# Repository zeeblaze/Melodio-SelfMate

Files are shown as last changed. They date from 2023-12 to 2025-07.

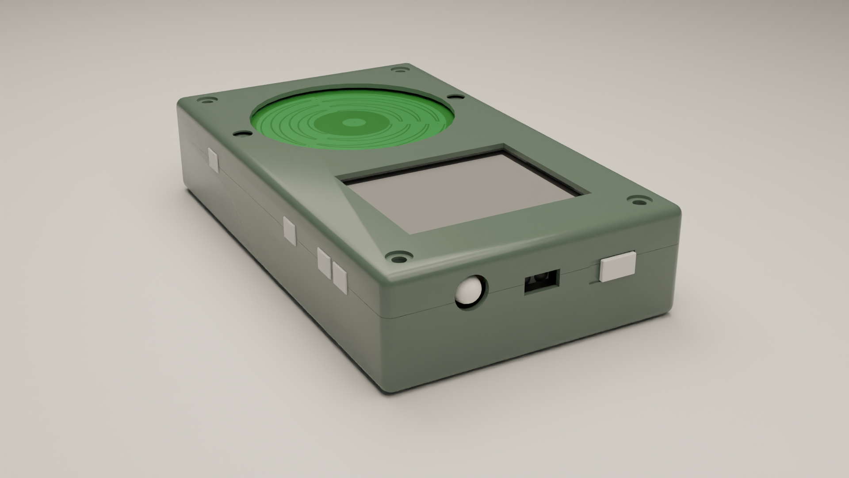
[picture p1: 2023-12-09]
Melodio_renders/R1.png

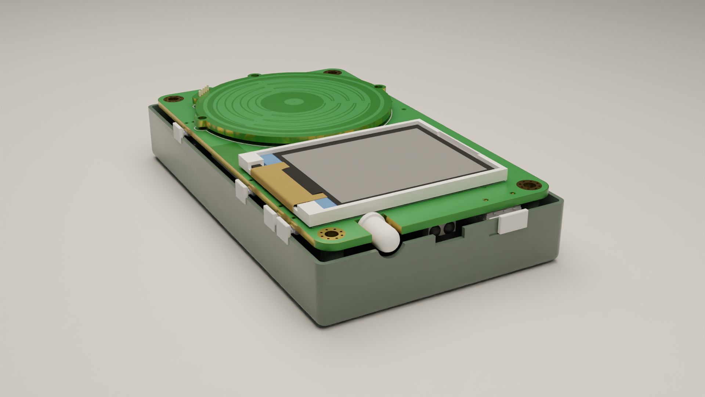
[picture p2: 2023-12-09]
Melodio_renders/R2.png

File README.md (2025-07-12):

Melodio Self-Mate is a cutting-edge portable electronic device designed to revolutionize your music experience. At its core lies the powerful ESP32-S3, providing unparalleled performance and versatility. This innovative gadget seamlessly combines music playback, Spotify streaming, and programmability, making it the go-to choice for music enthusiasts and programmers that wants to look into how smart devices work.

This portable programmable device packs a lot into its little brain, including and not Limited to, IR(receiver and transmitter), High speed mass storage, SD card, touch wheel technology, USB switch, which gives it a endless possibility of what is achievable with it. 

# KEY FEATURES:

ESP32-S3: Melodio makes use of ESP32-S3 as its heart which ensures high-performance and efficiency, enabling a seamless user experience.

DAC: Melodio uses the high quality TI PCM5102A 32bit, 348kHz, 112dB audio stereo DAC to output digital audio signal coming from the ESP32-S3 as analog signal for the headphone amplifier.

HEADPHONE AMP: High quality analog audio signal coming from the PCM5102A is received by yet another high quality headphone amplifier from Texas Instrument, TI TPA6130A2 138-mW stereo analog input headphone amplifier with I2C control interface, which then output its amplified audio signal to a headphone jack. The I2c control interface of this amplifier allows the volume of the amplifier output audio to be controlled from the software.

DISPLAY: Melodio implements a 1.8 inch 128x160 ST7735 TFT display as a visual interface.

MASS STORAGE

USB SWITCH

BUTTONS: There are four buttons on the side of Melodio:

Volume Up
Volume Down
Boot_0(for entering programming mode)
Reset
Volume Up and Volume Down buttons control the  headphone amp directly from software, so their functionalities can be altered and hardcode the amplifier volume directly from software. 

SLIDER SWITCHES

SPOTIFY CONNECT

MUSIC PLAYER

STEMMA QT CONNECTOR

IR (Transmitter and Receiver)

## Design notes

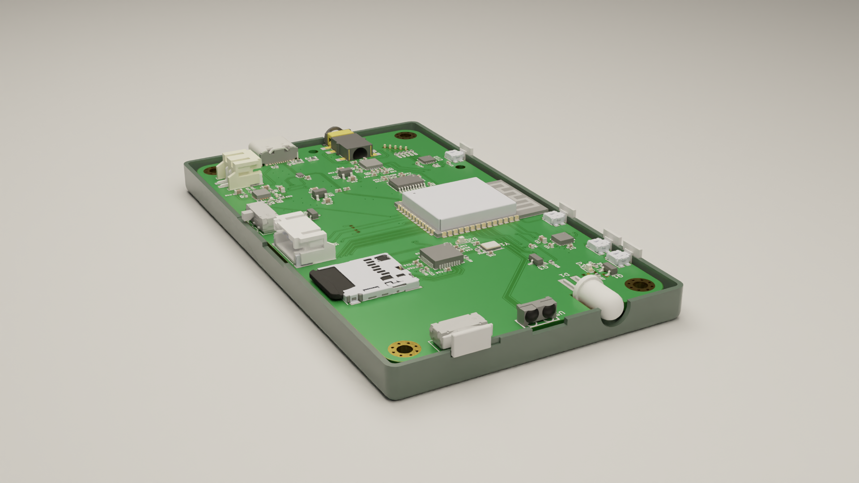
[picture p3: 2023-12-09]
Melodio_renders/R4.png

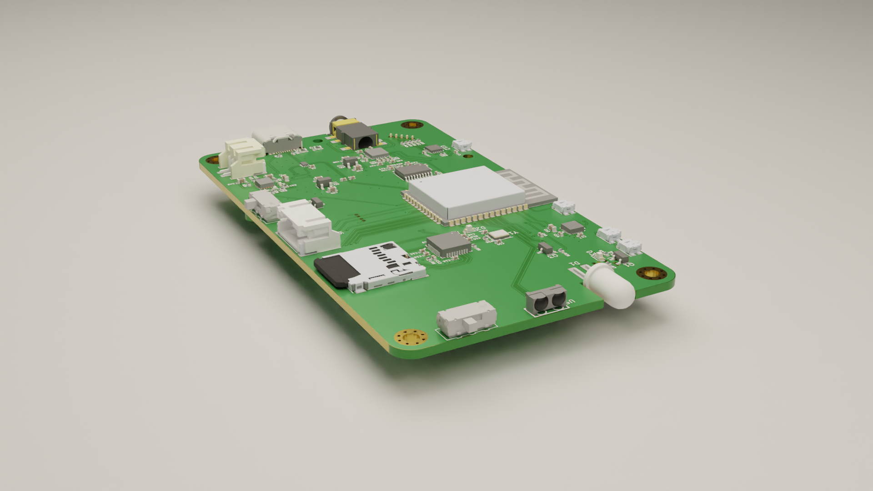
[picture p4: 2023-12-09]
Melodio_renders/R3.png

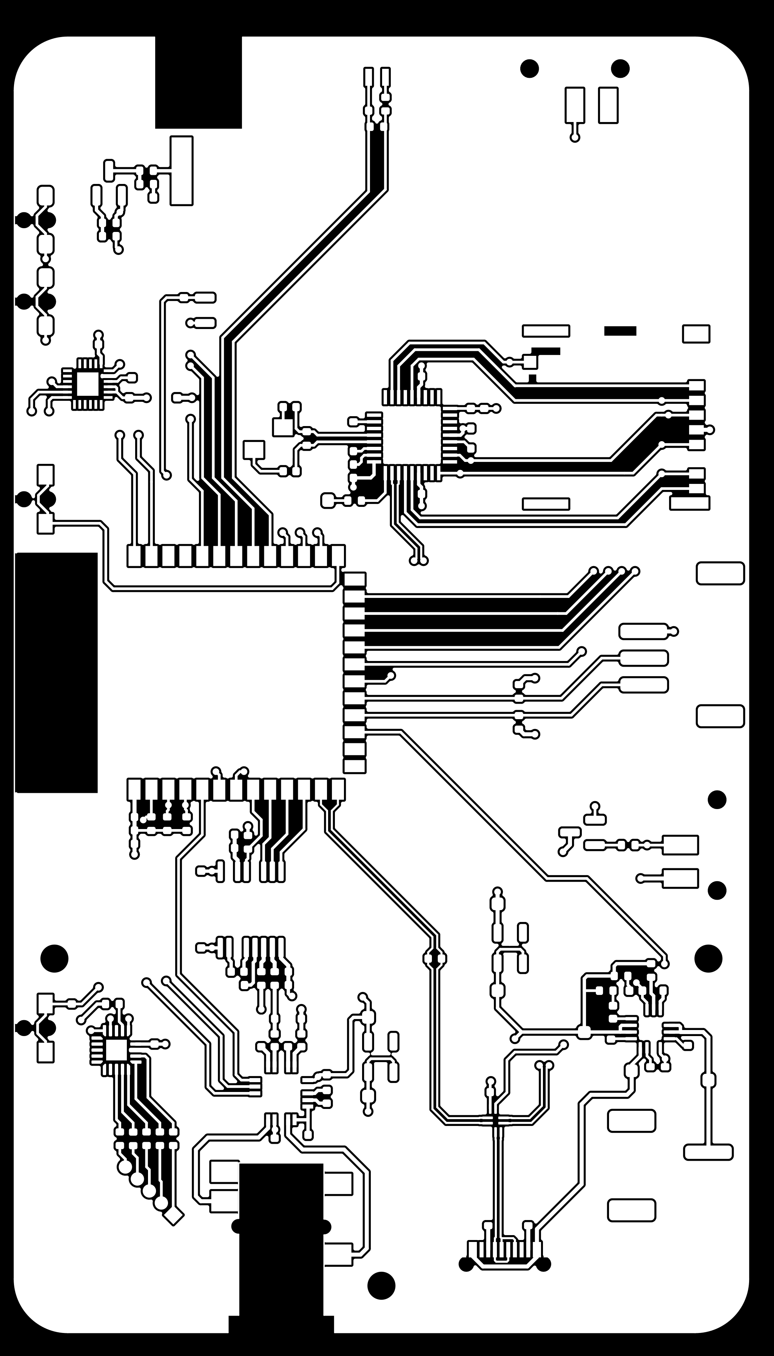
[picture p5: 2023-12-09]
Output_PNGs/pcb_F_CU.png

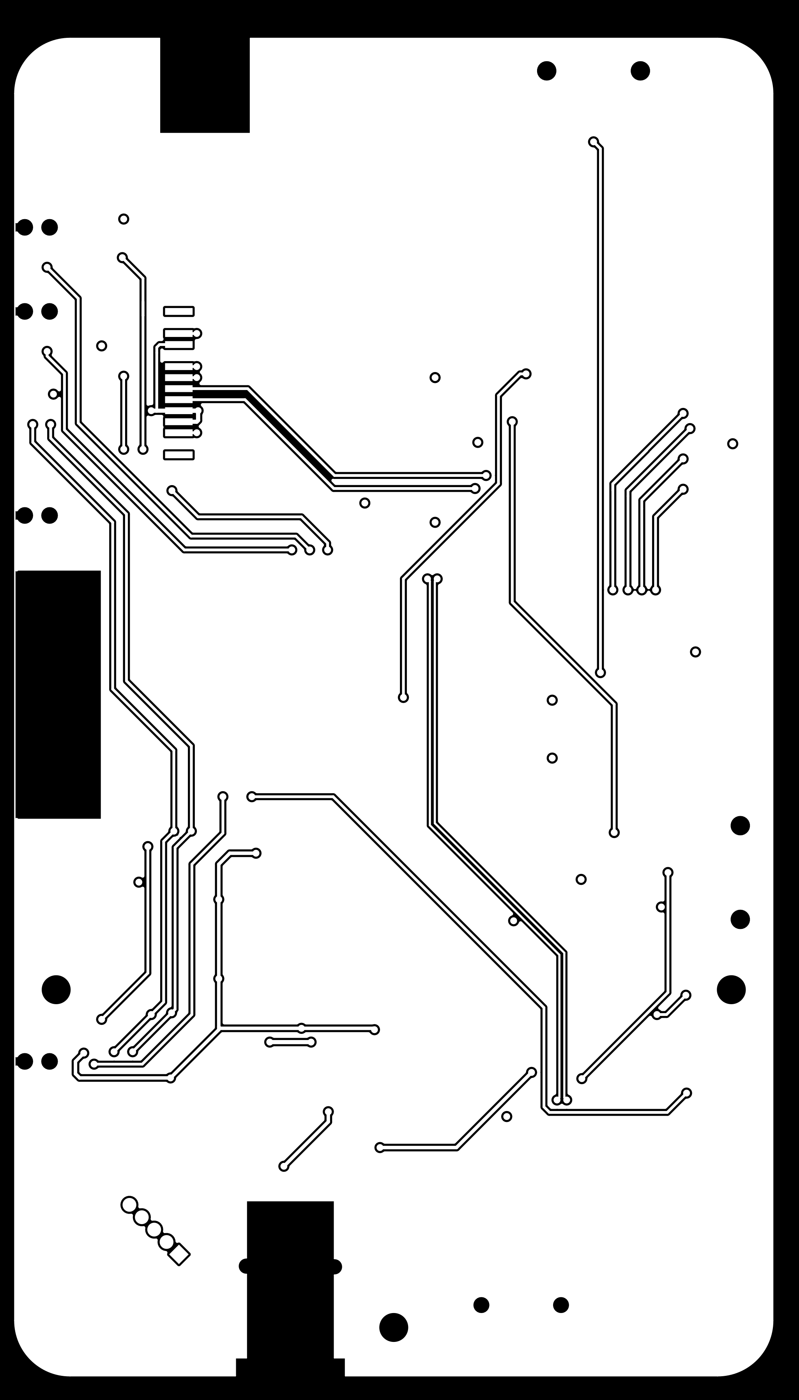
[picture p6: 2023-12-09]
Output_PNGs/pcb_B_Cu.png

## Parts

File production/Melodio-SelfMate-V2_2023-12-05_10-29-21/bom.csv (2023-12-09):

Designator | Footprint | Quantity | Value | LCSC Part #
C1, C11, C13 | 0402 | 3 | 10u
C10, C2, C20, C22, C35, C4, C5, C8, C9 | 0402 | 9 | 100n
C12, C17, C19, C21, C23, C24, C25, C26, C27, C28, C29, C3, C30, C31, C32, C33, C34, C36, C37, C38, C39, C44 | 0402 | 22 | 1u
C14, C16 | 0402 | 2 | 2n2
C15, C18 | 0402 | 2 | DNP
C40, C41, C42, C43, C45, C46, C47 | 0603 | 7 | 10u
C6, C7 | 0402 | 2 | 2u2
D1 | 0603 | 1 | GREEN
D2 | LED_5mm_Side_Mount | 1 | SFH4346
D3, D4 | 0402 | 2 | RED
D5 | 0402 | 1 | GREEN
H1, H2, H3, H4 | MountingHole_2.7mm_M2.5_Pad_Via | 4 | MountingHole_Pad
J1 | JST_PH_S4B-PH-SM4-TB_1x04-1MP_P2.00mm_Horizontal | 1 | STEMMA_QT
J2 | SMD_PJ-399E-6A | 1 | ~
J3 | USB_C_Receptacle_GCT_USB4105-xx-A_16P_TopMnt_Horizontal | 1 | USB_C_Receptacle_USB2.0
J4 | JST_PH_S2B-PH-SM4-TB_1x02-1MP_P2.00mm_Horizontal | 1 | BATTERY_CONN
J5 | PinHeader_1x05_P1.27mm_Vertical | 1 | Qtouch
J6 | MOLEX_503398-1892 | 1 | Micro_SD_Card_Det2
Q1, Q2, Q3 | SOT-23 | 3 | DMG2301L
R1, R11, R14, R17, R18, R2, R21, R22, R23, R25, R26, R27, R28, R29, R33, R34, R37, R8 | 0402 | 18 | 10k
R10 | 0402 | 1 | 330R
R12, R15, R31, R32, R9 | 0402 | 5 | 1k
R13 | 0402 | 1 | 200R
R16, R7 | 0402 | 2 | 1mR
R19, R20 | 0402 | 2 | 5k1
R24, R30 | 0402 | 2 | 1k1
R3, R4 | 0402 | 2 | 470R
R35, R36, R5, R6 | 0402 | 4 | 4k7
SW1 | SW_SPST_EVQP7C | 1 | BOOT
SW2 | SW_SPST_EVQP7C | 1 | RST
SW3, SW6 | SW_SPDT_CK-JS102011SAQN | 2 | SW_USB
SW4 | SW_SPST_EVQP7C | 1 | VOL_UP
SW5 | SW_SPST_EVQP7C | 1 | VOL_DOWN
U1 | TSSOP-20_4.4x6.5mm_P0.65mm | 1 | PCM5102
U10 | VQFN-16-1EP_3x3mm_P0.5mm_EP1.6x1.6mm | 1 | BQ24075RGT
U11 | VQFN-20-1EP_3x3mm_P0.45mm_EP1.55x1.55mm | 1 | ~
U12, U9 | SOT-23-5 | 2 | AP2112K-3.3
U2 | ESP32-S3-WROOM-1-N8R8 | 1 | ESP32-S3-WROOM-1-N4R4
U3 | UQFN-10_1.3x1.8mm_P0.4mm | 1 | USB3740B-AI2
U4 | MPU-6500 | 1 | MPU-6500
U5 | TPA6130A2RTJR | 1 | TPA6130A2RTJR | TPA6130A2RTJR
U6 | USB2244-AEZG-06 | 1 | USB2244-AEZG-06
U7 | IRM-V838M3-C-TR1 | 1 | ~
U8 | 1.8inch_TFT_128x160 | 1 | ~
Y1 | Crystal_SMD_3225-4Pin_3.2x2.5mm | 1 | 24MHz

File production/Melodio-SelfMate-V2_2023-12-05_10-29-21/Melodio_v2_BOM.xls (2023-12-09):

Manufacturer Part Number* | Qty* | Designator* | Customer Supply | Customer Remark
C0402X5R106M100NTBF | 3 | C1, C11, C13 | 10u | 402
0402B104J100NT | 9 | C10, C2, C20, C22, C35, C4, C5, C8, C9 | 100n | 402
0402X105K160NT | 22 | C12, C17, C19, C21, C23, C24, C25, C26, C27, C28, C29, C3, C30, C31, C32, C33, C34, C36, C37, C38, C39, C44 | 1u | 402
CC0402KRX7R6BB222 | 2 | C14, C16 | 2n2 | 402
DNP | 2 | C15, C18 | DNP | 402
TCC0603X5R106K250CT | 7 | C40, C41, C42, C43, C45, C46, C47 | 10u | 603
0402X225M6R3NT | 2 | C6, C7 | 2u2 | 402
LTST-C191TGKT | 1 | D1 | GREEN | 603
IR383-A | 1 | D2 | SFH4346 | LED_5mm_Side_Mount
XL-1005SURC | 2 | D3, D4 | RED | 402
LTST-C281KGKT | 1 | D5 | GREEN | 402
DNP | 4 | H1, H2, H3, H4 | MountingHole_Pad | MountingHole_2.7mm_M2.5_Pad_Via
S4B-PH-SM4-TB(LF)(SN) | 1 | J1 | STEMMA_QT | JST_PH_S4B-PH-SM4-TB_1x04-1MP_P2.00mm_Horizontal
PJ-399E-6A | 1 | J2 | ~ | SMD_PJ-399E-6A
USB4105-GF-A | 1 | J3 | USB_C_Receptacle_USB2.0 | USB_C_Receptacle_GCT_USB4105-xx-A_16P_TopMnt_Horizontal
S2B-PH-SM4-TB(LF)(SN) | 1 | J4 | BATTERY_CONN | JST_PH_S2B-PH-SM4-TB_1x02-1MP_P2.00mm_Horizontal
Pin headers XPB-210-1S-1*12P | 1 | J5 | Qtouch | PinHeader_1x05_P1.27mm_Vertical
MOLEX-5033981892 | 1 | J6 | Micro_SD_Card_Det2 | MOLEX_503398-1892
DMG2301L-7 | 3 | Q1, Q2, Q3 | DMG2301L | SOT-23
RC0402FR-0710KP | 18 | R1, R11, R14, R17, R18, R2, R21, R22, R23, R25, R26, R27, R28, R29, R33, R34, R37, R8 | 10k | 402
ARG02DTC3300 | 1 | R10 | 330R | 402
RC0402DR-071KL | 5 | R12, R15, R31, R32, R9 | 1k | 402
AC0402JR-07200RL | 1 | R13 | 200R | 402
AC0402JR-071ML | 2 | R16, R7 | 1mR | 402
RC0402JR-075K1L | 2 | R19, R20 | 5k1 | 402
RC0402FR-071K1L | 2 | R24, R30 | 1k1 | 402
AC0402JR-07470RL | 2 | R3, R4 | 470R | 402
RC0402DR-074K7L | 4 | R35, R36, R5, R6 | 4k7 | 402
EVQP7C01P | 1 | SW1 | BOOT | SW_SPST_EVQP7C
EVQP7C01P | 1 | SW2 | RST | SW_SPST_EVQP7C
C&K JS102011SAQN | 2 | SW3, SW6 | SW_USB | SW_SPDT_CK-JS102011SAQN
EVQP7C01P | 1 | SW4 | VOL_UP | SW_SPST_EVQP7C
EVQP7C01P | 1 | SW5 | VOL_DOWN | SW_SPST_EVQP7C
PCM5102APWR | 1 | U1 | PCM5102 | TSSOP-20_4.4x6.5mm_P0.65mm
DNP | 1 | U10 | BQ24075RGT | VQFN-16-1EP_3x3mm_P0.5mm_EP1.6x1.6mm
AT42QT2120-MMH | 1 | U11 | ~ | VQFN-20-1EP_3x3mm_P0.45mm_EP1.55x1.55mm
AP2112K-3.3TRG1 | 2 | U12, U9 | AP2112K-3.3 | SOT-23-5
ESP32-S3-WROOM-1-N4R4 | 1 | U2 | ESP32-S3-WROOM-1-N4R4 | ESP32-S3-WROOM-1-N4R4
USB3740B-AI2 | 1 | U3 | USB3740B-AI2 | UQFN-10_1.3x1.8mm_P0.4mm
DNP | 1 | U4 | MPU-6500 | MPU-6500
TPA6130A2RTJR | 1 | U5 | TPA6130A2RTJR | TPA6130A2RTJR
USB2244-AEZG-06 | 1 | U6 | USB2244-AEZG-06 | USB2244-AEZG-06
IRM-V838M3-C-TR1 | 1 | U7 | ~ | IRM-V838M3-C-TR1
DNP | 1 | U8 | ~ | 1.8inch_TFT_128x160
XXCBCLNAOF-24MHz | 1 | Y1 | 24MHz | Crystal_SMD_3225-4Pin_3.2x2.5mm

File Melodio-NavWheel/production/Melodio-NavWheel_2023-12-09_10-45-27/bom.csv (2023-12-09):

Designator | Footprint | Quantity | Value | LCSC Part #
J1 | qtouch-wheel | 1 | Wheel
J2 | qtouch-button | 1 | Sel
J3 | qtouch-guard | 1 | Guard
J4 | PinHeader_1x05_P1.27mm_Vertical | 1 | Interface

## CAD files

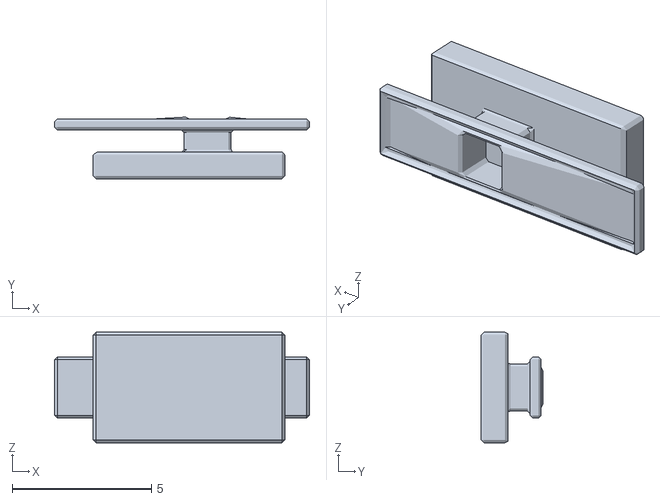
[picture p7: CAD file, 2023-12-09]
Melodio 3D print/Melodio_Case_Slider.stl
9.16 x 2.22 x 3.97

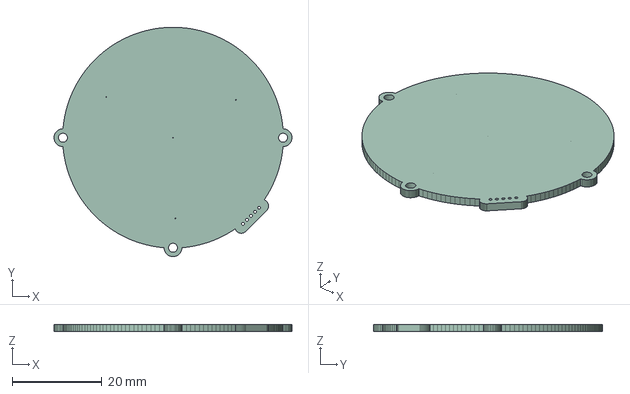
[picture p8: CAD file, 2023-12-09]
Melodio-NavWheel/Melodio-NavWheel.step
53.0 x 51.1 x 1.60 mm

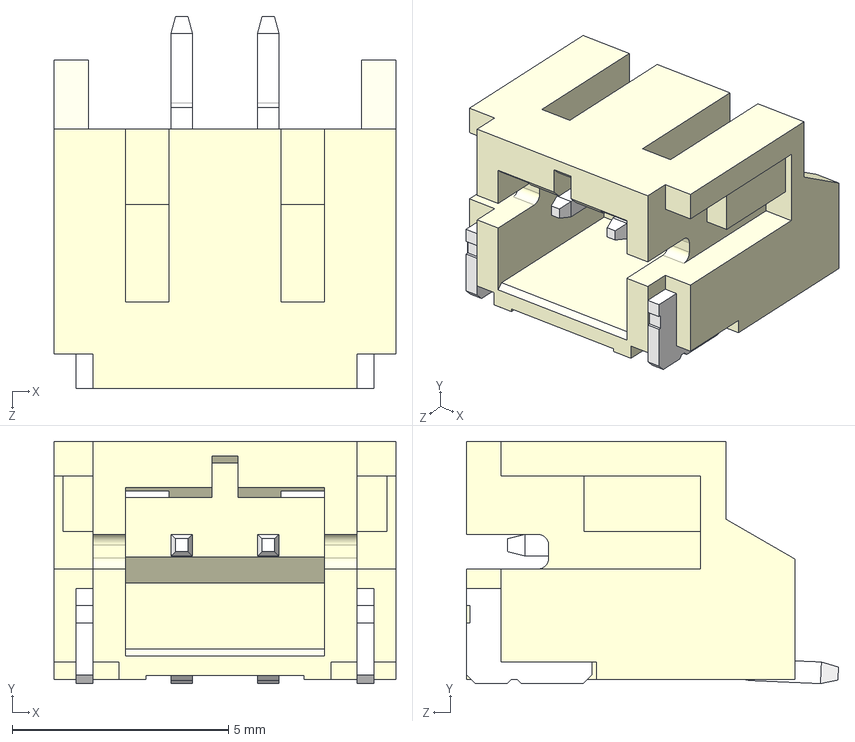
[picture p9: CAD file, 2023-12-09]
Melodio-SelfMate-V2-3Dmodels/S2B-PH-SM4-TB(LF)(SN)--3DModel-STEP-56544.STEP
7.90 x 5.60 x 8.60 mm

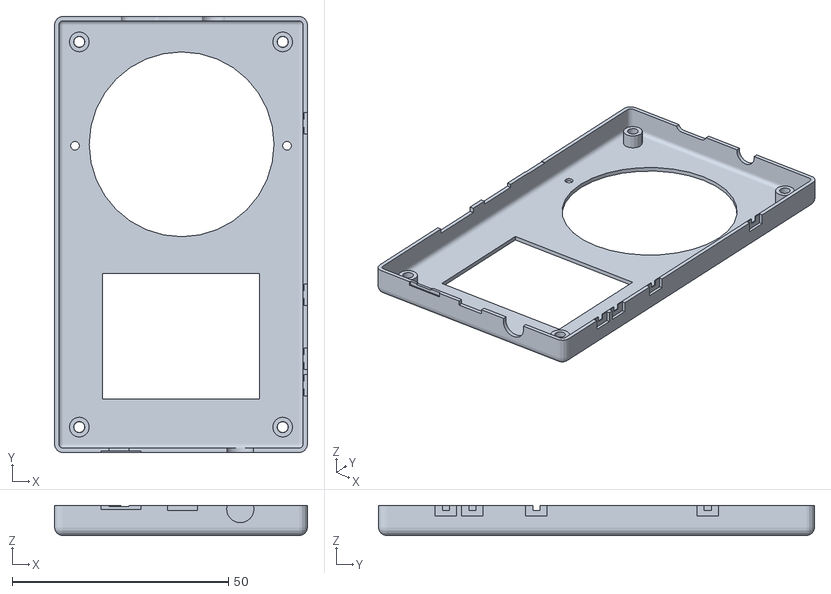
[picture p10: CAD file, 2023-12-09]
Melodio 3D print/Melodio_Case_Top.stl
58.5 x 100.8 x 6.98

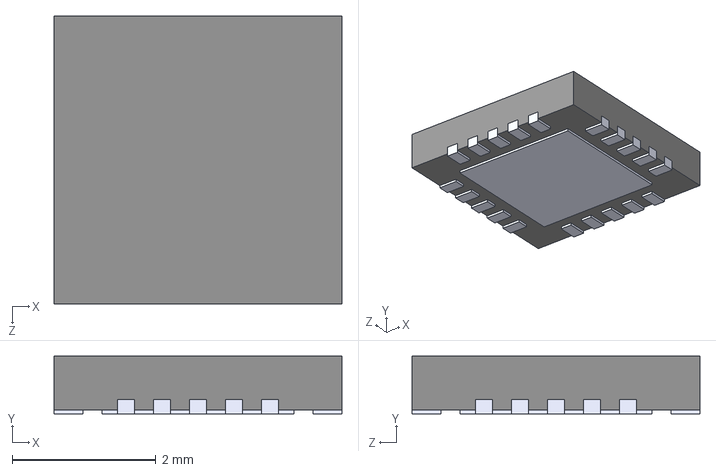
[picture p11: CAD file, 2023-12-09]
Melodio-SelfMate-V2-3Dmodels/TPA6130A2RTJR.step
4.00 x 0.8 x 4.00 mm

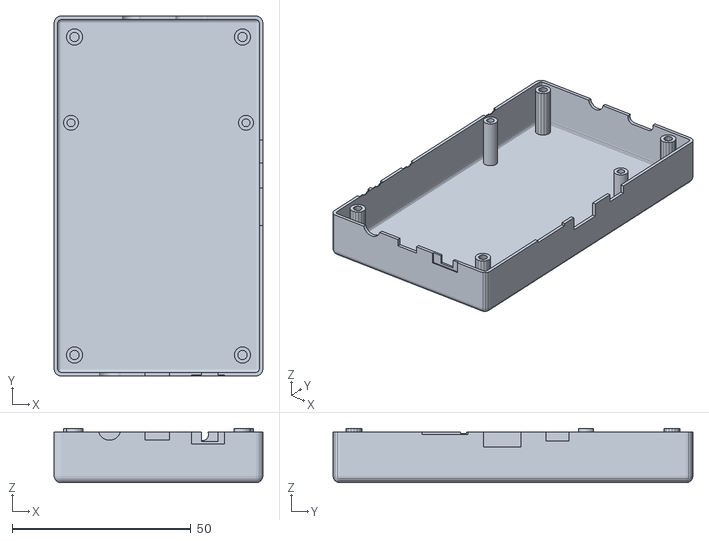
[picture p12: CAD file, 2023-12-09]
Melodio 3D print/Melodio_Case_Base.stl
58.5 x 100.8 x 15.3

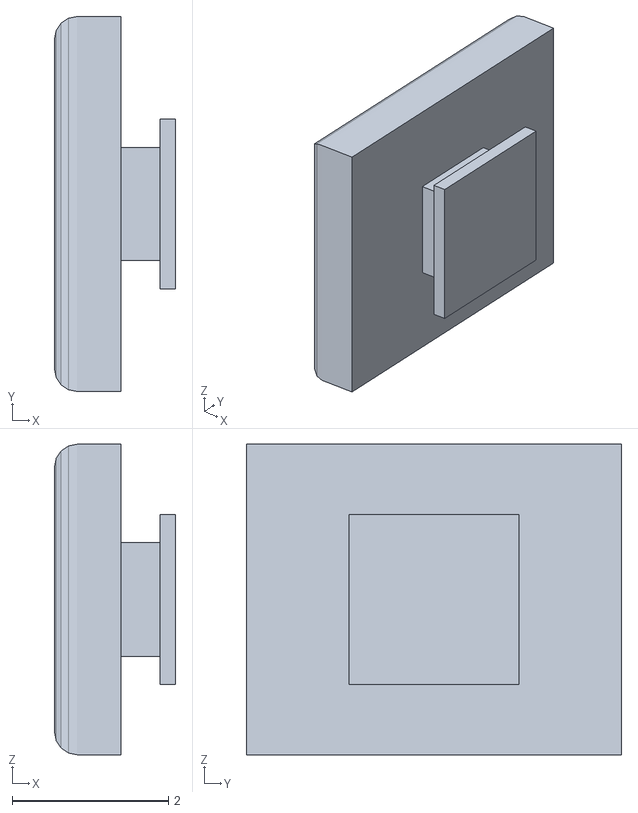
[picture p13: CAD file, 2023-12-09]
Melodio 3D print/Melodio_Case_Button.stl
1.55 x 4.80 x 3.98

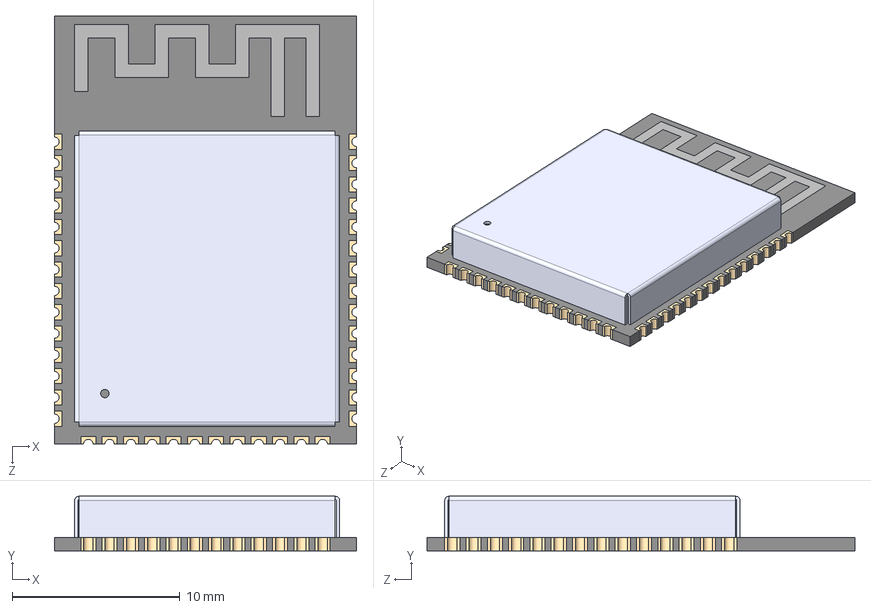
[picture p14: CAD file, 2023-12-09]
Melodio-SelfMate-V2-3Dmodels/ESP32-S3-WROOM-1-N8R8.step
18.0 x 3.25 x 25.5 mm

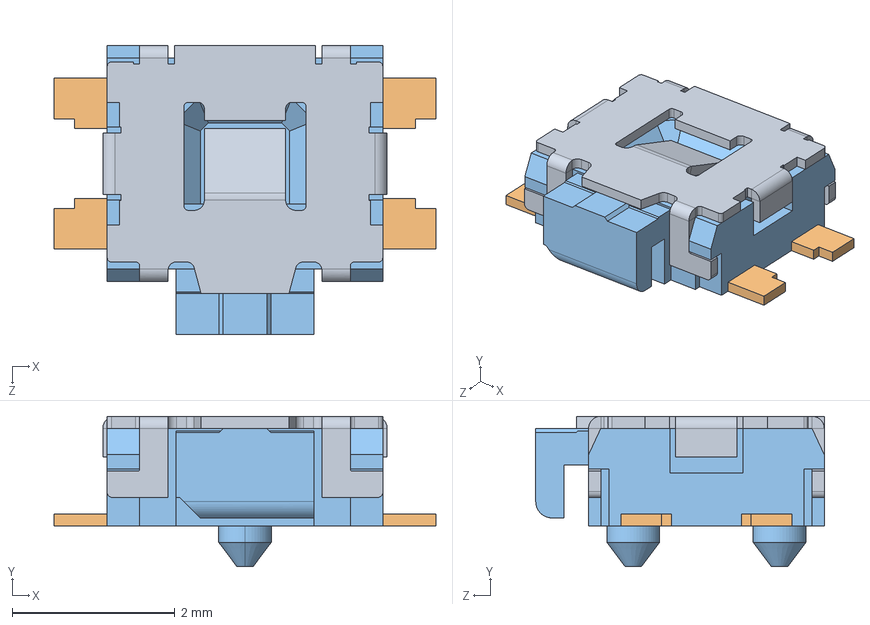
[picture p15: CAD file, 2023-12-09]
Melodio-SelfMate-V2-3Dmodels/EVQP7C01P--3DModel-STEP-269445.STEP
4.70 x 1.85 x 3.55 mm

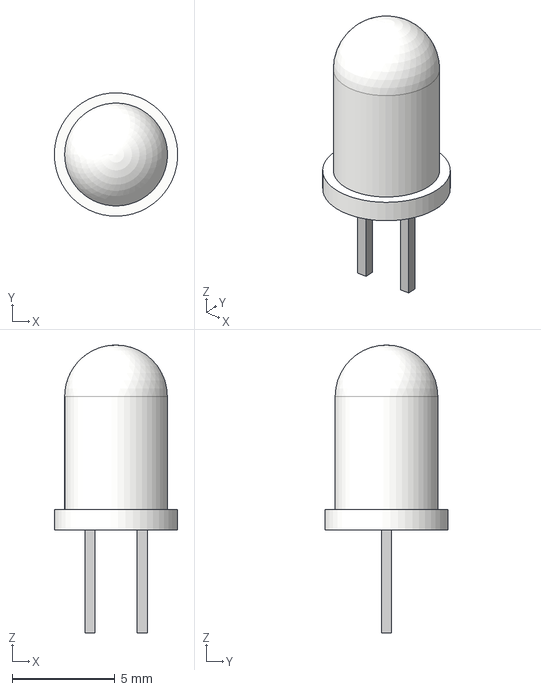
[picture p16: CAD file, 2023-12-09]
Melodio-SelfMate-V2-3Dmodels/Side Mount LED v1.step
5.99 x 6.00 x 14.0 mm

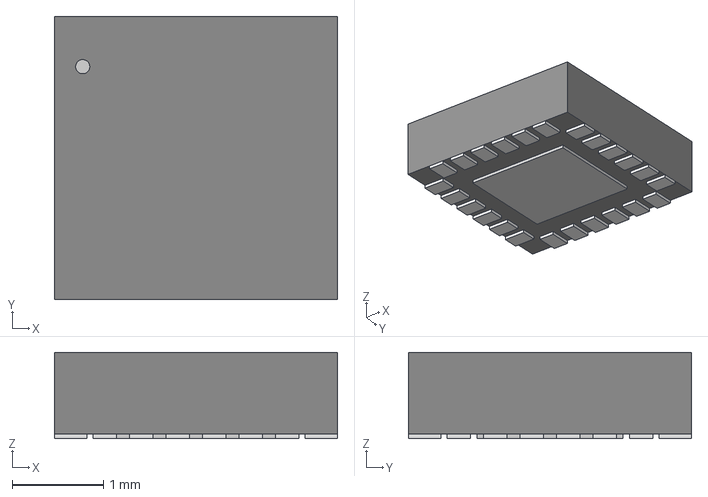
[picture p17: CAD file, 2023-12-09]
Melodio-SelfMate-V2-3Dmodels/MPU6500.step
3.10 x 3.10 x 0.942 mm

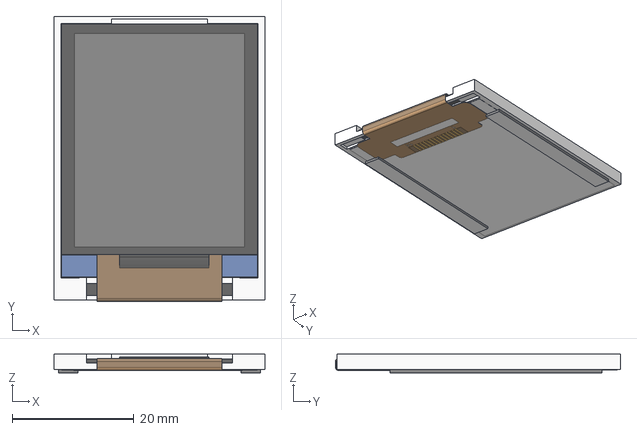
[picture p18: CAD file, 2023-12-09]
Melodio-SelfMate-V2-3Dmodels/LCD_TFT_1.8_SPI_ST7735.stp
34.7 x 46.9 x 3.07 mm

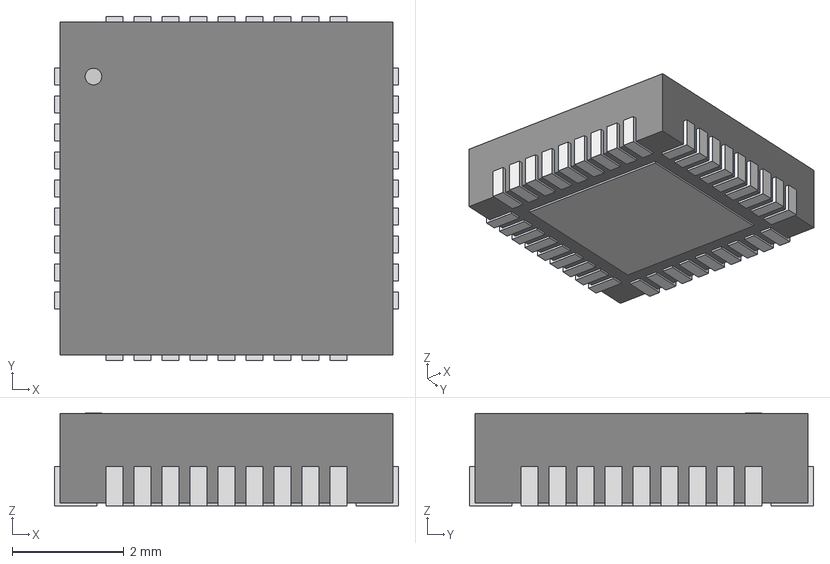
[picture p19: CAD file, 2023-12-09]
Melodio-SelfMate-V2-3Dmodels/USB2244-AEZG-06.step
6.15 x 6.15 x 1.65 mm

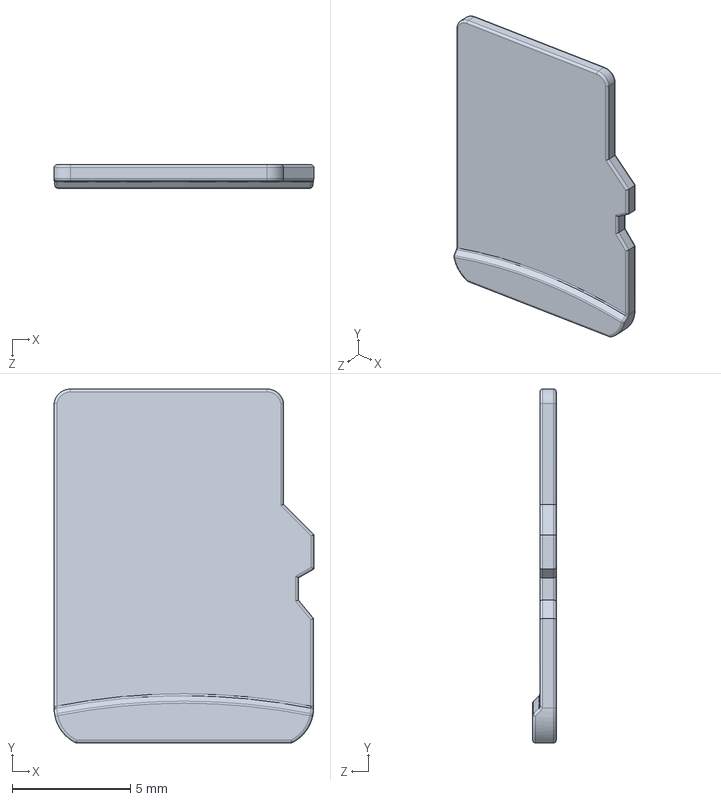
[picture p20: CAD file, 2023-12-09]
Melodio-SelfMate-V2-3Dmodels/Micro SD Card.STEP
11.0 x 15.0 x 1.00 mm

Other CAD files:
Melodio-SelfMate-V2-3Dmodels/S4B-PH-SM4-TB--3DModel-STEP-56544.STEP
Melodio-SelfMate-V2-3Dmodels/BQ24075RGTRG4.stp
Melodio-SelfMate-V2-3Dmodels/503398-1892.step
Melodio-SelfMate-V2-3Dmodels/JS102011SAQN--3DModel-Eagle-1.STEP

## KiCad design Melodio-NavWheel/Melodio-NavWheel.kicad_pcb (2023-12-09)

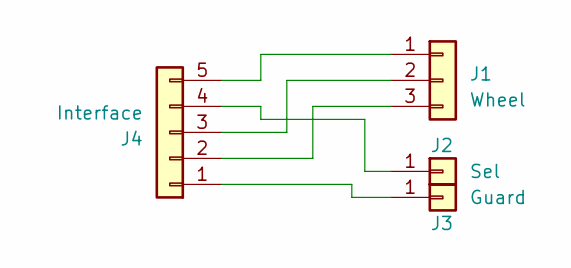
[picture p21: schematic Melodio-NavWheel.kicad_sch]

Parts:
J1: Wheel; qtouch-wheel
J2: Sel; qtouch-button
J3: Guard; qtouch-guard
J4: Interface; PinHeader_1x05_P1.27mm_Vertical

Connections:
unnamed: J1.1, J4.5
unnamed: J1.2, J4.3
unnamed: J1.3, J4.2
unnamed: J2.1, J4.4
unnamed: J3.1, J4.1

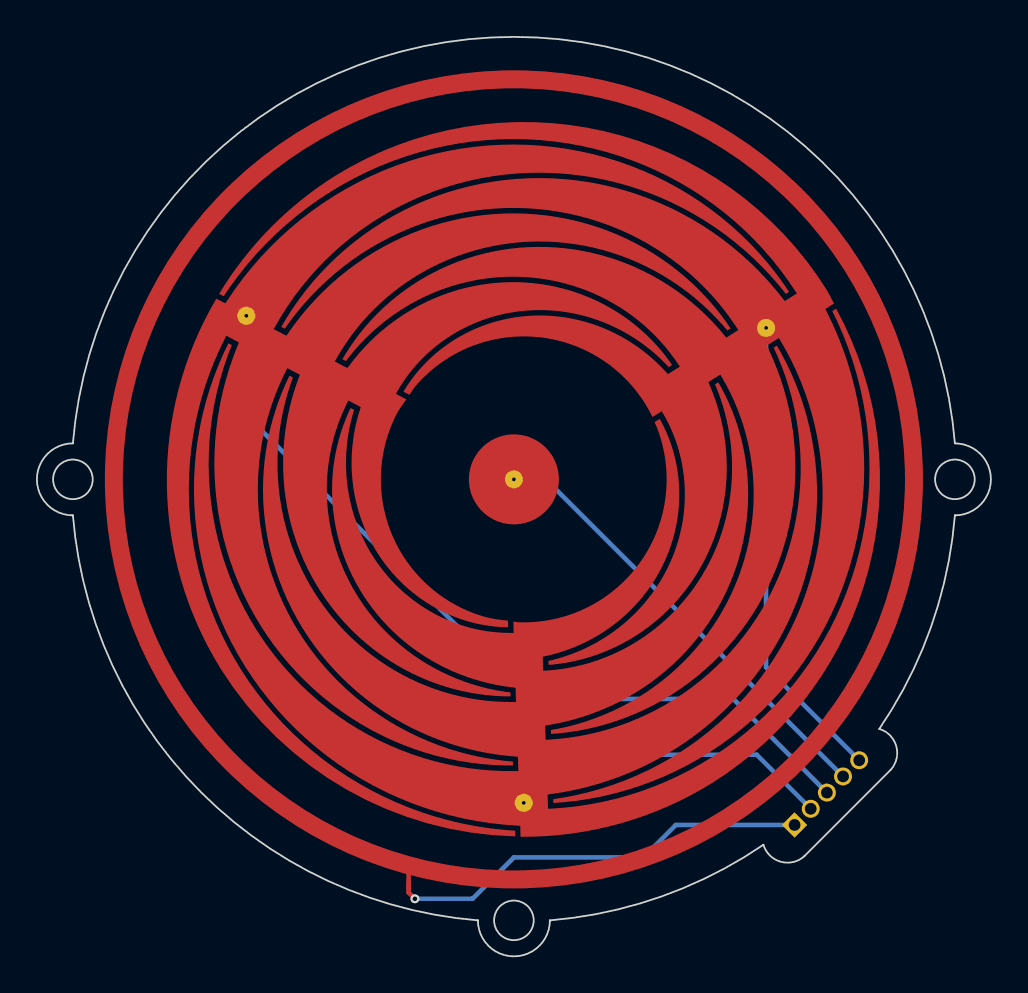
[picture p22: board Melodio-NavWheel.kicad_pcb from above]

Board: 2 copper layers, 53.0 x 51.1 mm, 4 parts (1 on the bottom side), 5 nets.

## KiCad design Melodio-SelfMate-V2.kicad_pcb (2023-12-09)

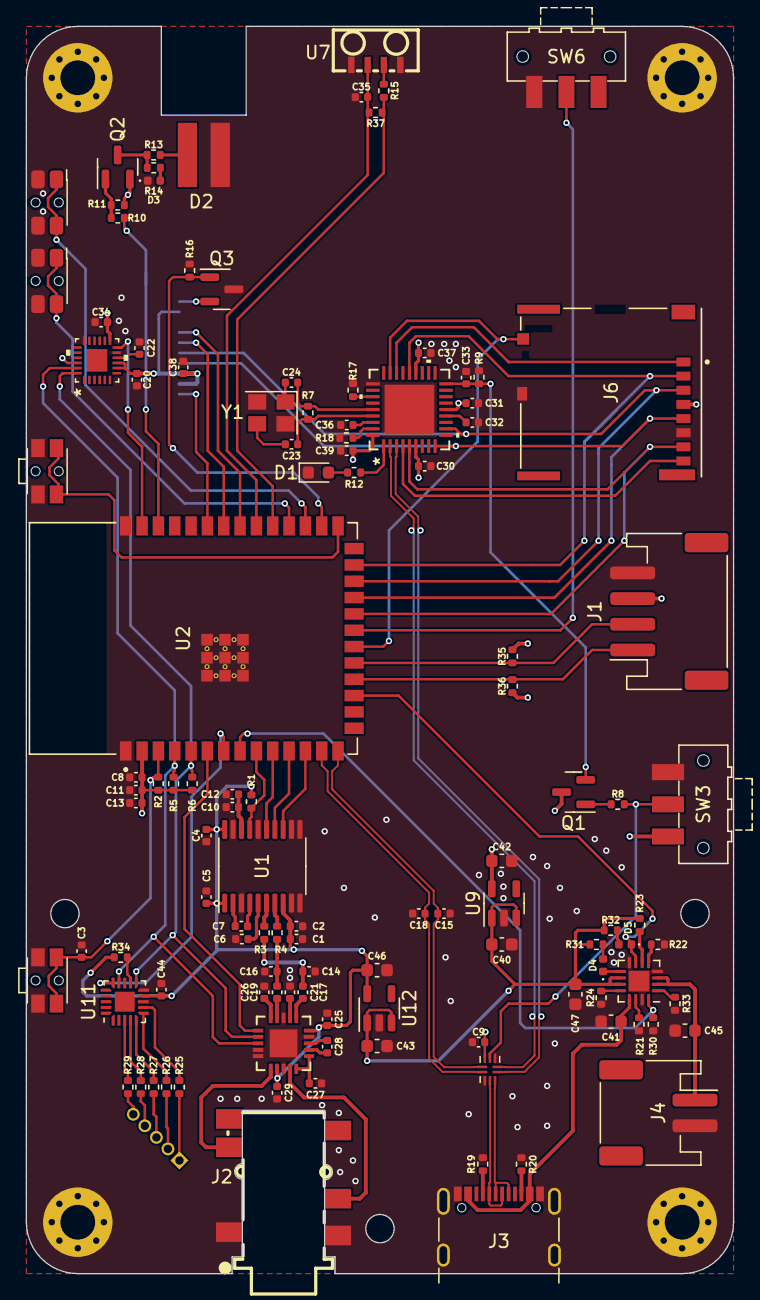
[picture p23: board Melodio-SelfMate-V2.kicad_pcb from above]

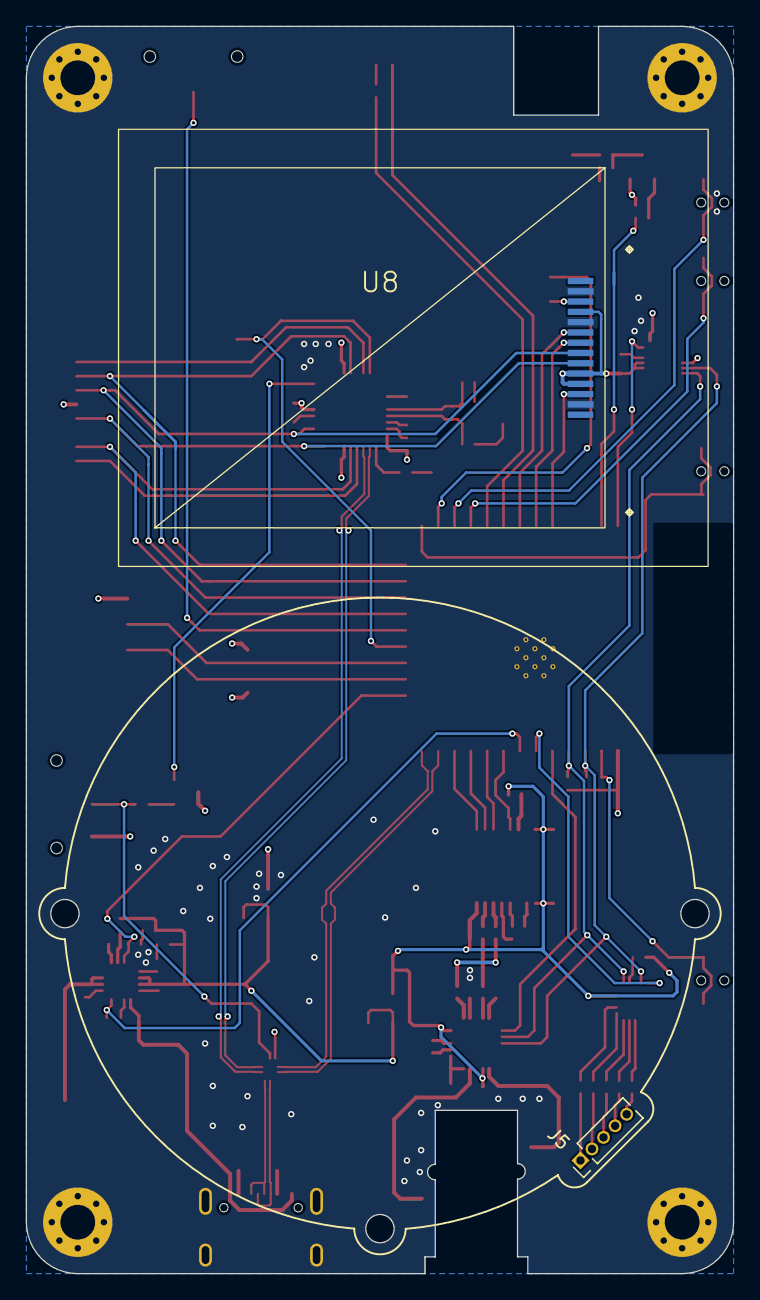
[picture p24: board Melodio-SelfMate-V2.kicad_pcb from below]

Board: 4 copper layers, 55.0 x 97.0 mm, 121 parts (2 on the bottom side), 102 nets.

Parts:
C1, C11, C13: 10u; C_0402_1005Metric
C2, C4, C5, C8, C9, C10, C20, C22, C35: 100n; C_0402_1005Metric
C3, C12, C17, C19, C21, C23, C24, C25, C26, C27, C28, C29, C30, C31, C32, C33, C34, C36, C37, C38, C39, C44: 1u; C_0402_1005Metric
C6, C7: 2u2; C_0402_1005Metric
C14, C16: 2n2; C_0402_1005Metric
C15, C18: DNP; C_0402_1005Metric
C40, C41, C42, C43, C45, C46, C47: 10u; C_0603_1608Metric
D1: GREEN; LED_0603_1608Metric
D2: SFH4346; LED_5mm_Side_Mount
D3, D4: RED; LED_0402_1005Metric
D5: GREEN; LED_0402_1005Metric
H1, H2, H3, H4: MountingHole_Pad; MountingHole_2.7mm_M2.5_Pad_Via
J1: STEMMA_QT; JST_PH_S4B-PH-SM4-TB_1x04-1MP_P2.00mm_Horizontal
J2: SMD_PJ-399E-6A
J3: USB_C_Receptacle_USB2.0; USB_C_Receptacle_GCT_USB4105-xx-A_16P_TopMnt_Horizontal
J4: BATTERY_CONN; JST_PH_S2B-PH-SM4-TB_1x02-1MP_P2.00mm_Horizontal
J5: Qtouch; PinHeader_1x05_P1.27mm_Vertical
J6: Micro_SD_Card_Det2; MOLEX_503398-1892
Q1, Q2, Q3: DMG2301L; SOT-23
R1, R2, R8, R11, R14, R17, R18, R21, R22, R23, R25, R26, R27, R28, R29, R33, R34, R37: 10k; R_0402_1005Metric
R3, R4: 470R; R_0402_1005Metric
R5, R6, R35, R36: 4k7; R_0402_1005Metric
R7, R16: 1mR; R_0402_1005Metric
R9, R12, R15, R31, R32: 1k; R_0402_1005Metric
R10: 330R; R_0402_1005Metric
R13: 200R; R_0402_1005Metric
R19, R20: 5k1; R_0402_1005Metric
R24, R30: 1k1; R_0402_1005Metric
SW1: BOOT; SW_SPST_EVQP7C
SW2: RST; SW_SPST_EVQP7C
SW3, SW6: SW_USB; SW_SPDT_CK-JS102011SAQN
SW4: VOL_UP; SW_SPST_EVQP7C
SW5: VOL_DOWN; SW_SPST_EVQP7C
U1: PCM5102; TSSOP-20_4.4x6.5mm_P0.65mm
U2: ESP32-S3-WROOM-1-N4R4; ESP32-S3-WROOM-1-N8R8
U3: USB3740B-AI2; UQFN-10_1.3x1.8mm_P0.4mm
U4: MPU-6500
U5: TPA6130A2RTJR
U6: USB2244-AEZG-06
U7: IRM-V838M3-C-TR1
U8: 1.8inch_TFT_128x160
U9, U12: AP2112K-3.3; SOT-23-5
U10: BQ24075RGT; VQFN-16-1EP_3x3mm_P0.5mm_EP1.6x1.6mm
U11: VQFN-20-1EP_3x3mm_P0.45mm_EP1.55x1.55mm
Y1: 24MHz; Crystal_SMD_3225-4Pin_3.2x2.5mm

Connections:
+3.3VA: C1.2, C2.2, C4.2, C5.2, C25.1, C29.1, C44.2, C46.1, R1.2, R34.2, U1.1 (CPVDD), U1.8 (AVDD), U1.20 (DVDD), U5.12 (VDD_2), U5.20 (VDD), U11.9 (VDD), U12.5 (VOUT)
+3V3: C8.1, C9.2, C11.1, C13.1, C20.1, C30.2, C31.2, C34.1, C37.2, C38.1, C39.2, C42.1, J1.3, J6.4 (VDD), Q1.3 (D), Q2.2 (S), R2.1, R5.2, R6.2, R11.1, R35.2, R36.2, SW3.1 (A), U2.2 (3V3), U3.5 (VDD), U4.8 (VDDIO), U4.9 (SDO/ADO), U4.13 (VDD), U4.22 (nCS), U6.6 (VDD33), U6.14 (VDD33), U6.22 (VDD33), U6.36 (VDDA33), U8.4 (LEDA), U8.10 (VCC), U8.11 (VCC2), U9.5 (VOUT)
+5V: C40.1, C43.1, C47.1, R23.2, R31.1, R32.1, U9.1 (VIN), U9.3 (EN), U10.10 (OUT), U10.11 (OUT), U12.1 (VIN), U12.3 (EN)
+BATT: C45.1, J4.1, U10.2 (BAT), U10.3 (BAT)
/CHG: D5.1 (K), U2.17 (IO9), U10.7 (~PGOOD)
/DISP_CS: U2.35 (IO42), U8.12 (CS)
/DISP_EN: Q3.1 (G), R16.2, U2.28 (IO35)
/DISP_RS: U2.34 (IO41), U8.7 (RS/DC)
/DISP_RST: U2.33 (IO40), U8.6 (RESET)
/EN1: R23.1, U10.6 (EN1)
/EN2: R22.2, U10.5 (EN2)
/HP_OUTL: J2.3, U5.14 (HPLEFT)
/HP_OUTR: J2.4, U5.11 (HPRIGHT)
/I2C1_SCL: J1.1, R36.1, U2.18 (IO10)
/I2C1_SDA: J1.2, R35.1, U2.19 (IO11)
/IMU_INT: U2.39 (IO1), U4.12 (INT)
/IO0: SW1.1, U2.27 (IO0)
/IR_LED: R10.1, U2.38 (IO2)
/IR_RX: R15.1, R37.1, U2.31 (IO38)
/IR_VCC: C35.2, R37.2, U2.32 (IO39), U7.2 (VCC)
/LOCK: SW6.2 (B), U2.21 (IO13)
/L_OUT: R3.1, U1.6 (OUTL)
/R_OUT: R4.1, U1.7 (OUTR)
/SD_CLK: J6.5 (CLK), U2.23 (IO21), U6.9 (SD_CLK), U8.9 (CLOCK)
/SD_CMD: J6.3 (CMD), U2.24 (IO47), U6.11 (SD_CMD), U8.8 (DATA)
/SD_CS: J6.2 (DAT3/CD), U2.25 (IO48), U6.23 (SD_D3)
/SD_DAT0: J6.7 (DAT0), U2.22 (IO14), U6.5 (SD_D0)
/SD_DAT1: J6.8 (DAT1), U6.4 (SD_D1)
/SD_DAT2: J6.1 (DAT2), U6.25 (SD_D2)
/SD_DET: J6.9 (DET), U2.20 (IO12), U6.26 (SD_NCD)
/TOUCH_INT: U2.7 (IO7), U11.15 (~CHANGE)
/USB1_D+: U3.2 (DP_1), U6.2 (USB+)
/USB1_D-: U3.1 (DM_1), U6.3 (USB-)
/USB2_D+: C15.1, U2.14 (IO20), U3.6 (DP_2)
/USB2_D-: C18.1, U2.13 (IO19), U3.7 (DM_2)
/USB_SW: R8.2, SW3.2 (B), U3.4 (S)
/VBUS: C41.1, J3.A4 (VBUS), J3.A9 (VBUS), J3.B4 (VBUS), J3.B9 (VBUS), U10.13 (IN)
/VOL_DOWN: SW5.1, U2.30 (IO37)
/VOL_UP: SW4.1, U2.29 (IO36)
/XIN: C23.2, R7.2, U6.33 (XTAL1(CLKIN))
/XTAL2: C24.2, R7.1, U6.32 (XTAL2)
AMP_SD: U2.6 (IO6), U5.6 (~SD)
CHG_ADC: R30.2, U2.8 (IO15), U10.16 (ISET)
DIN: U1.14 (DIN), U2.11 (IO18)
GND: C1.1, C2.1, C3.2, C4.1, C5.1, C6.1, C8.2, C9.1, C10.1, C11.2, C12.1, C13.2, C14.1, C15.2, C16.1, C18.2, C20.2, C21.2, C22.1, C25.2, C26.2, C27.1, C29.2, C30.1, C31.1, C32.2, C33.1, C34.2, C35.1, C36.1, C37.1, C38.2, C39.1, C40.2, C41.2, C42.2, C43.2, C44.1, C45.2, C46.2, C47.2, D1.1 (K), D2.1 (K), D3.1 (K), H1.1, H2.1, H3.1, H4.1, J1.4, J2.1, J2.2, J3.A1 (GND), J3.A12 (GND), J3.B1 (GND), J3.B12 (GND), J3.S1 (SHIELD), J4.2, J6.6 (VSS), J6.10 (SHIELD), Q3.3 (D), R9.1, R16.1, R17.1, R18.2, R19.2, R20.1, R21.1, R22.1, R24.1, R30.1, R33.2, SW1.2, SW2.2, SW3.3 (C), SW4.2, SW5.2, SW6.3 (C), U1.3 (CPGND), U1.9 (AGND), U1.10 (DEMP), U1.11 (FLT), U1.12 (SCK), U1.16 (FMT), U1.19 (DGND), U2.1 (GND), U2.40 (GND__1), U2.41_1 (GND__2), U2.41_2 (GND__3), U2.41_3 (GND__4), U2.41_4 (GND__5), U2.41_5 (GND__6), U2.41_6 (GND__7), U2.41_7 (GND__8), U2.41_8 (GND__9), U2.41_9 (GND__10), U3.3 (OE_N), U3.8 (GND), U4.11 (FSYNC), U4.18 (GND), U5.3 (GND_2), U5.9 (GND_3), U5.10 (GND_4), U5.13 (GND_5), U5.19 (GND), U5.21 (EP), U6.28 (TEST), U6.37 (EPAD), U7.1 (GND), U7.4 (GND), U8.2 (GND), U8.5 (GND1), U8.13 (GND2), U9.2 (GND), U10.4 (~CE), U10.8 (VSS), U10.15 (SYSOFF), U10.17 (VSS), U11.8 (VSS), U11.10 (MODE), U12.2 (GND), Y1.2, Y1.4
I2C_SCL: R5.1, U2.4 (IO4), U4.23 (SCL/SCLK), U5.8 (SCL), U11.14 (SCL)
I2C_SDA: R6.1, U2.5 (IO5), U4.24 (SDA/SDI), U5.7 (SDA), U11.11 (SDA)
I2S_BCLK: U1.13 (BCK), U2.12 (IO8)
I2S_LRCLK: U1.15 (LRCK), U2.10 (IO17)
MUTE: R1.1, U1.17 (XSMT), U2.9 (IO16)
unnamed: C14.2, C17.2, R3.2
unnamed: C16.2, C19.2, R4.2
unnamed: C23.1, Y1.3
unnamed: C24.1, Y1.1
unnamed: D1.2 (A), R12.2
unnamed: D2.2 (A), R13.2
unnamed: D3.2 (A), R14.2
unnamed: D4.2 (A), R31.2
unnamed: D4.1 (K), U10.9 (~CHG)
unnamed: D5.2 (A), R32.2
unnamed: J3.A5 (CC1), R19.1
unnamed: J3.B5 (CC2), R20.2
unnamed: J5.1, R25.1
unnamed: J5.2, R26.1
unnamed: J5.3, R27.1
unnamed: J5.4, R28.1
unnamed: J5.5, R29.1
unnamed: Q1.1 (G), R8.1
unnamed: C33.2, Q1.2 (S), R9.2, U6.18 (RESET_N)
unnamed: Q2.3 (D), R13.1, R14.1
unnamed: Q2.1 (G), R10.2, R11.2
unnamed: Q3.2 (S), U8.3 (LEDK)
unnamed: C7.1, U1.4 (CAPM)
unnamed: C7.2, U1.2 (CAPP)
unnamed: C10.2, C12.2, U1.18 (LDOO)
unnamed: C6.2, U1.5 (VNEG)
unnamed: C3.1, R2.2, SW2.1, U2.3 (EN)
unnamed: C22.2, U4.10 (REGOUT)
unnamed: C28.2, U5.17 (CPN)
unnamed: C28.1, U5.18 (CPP)
unnamed: C27.2, U5.15 (CPVSS_2), U5.16 (CPVSS)
unnamed: C17.1, U5.1 (LEFTINM)
unnamed: C21.1, U5.2 (LEFTINP)
unnamed: C26.1, U5.5 (RIGHTINM)
unnamed: C19.1, U5.4 (RIGHTINP)
unnamed: R12.1, U6.1 (LED)
unnamed: R18.1, U6.35 (RBIAS)
unnamed: R17.2, U6.30 (SD_WP)
unnamed: C32.1, U6.13 (VDD18)
unnamed: C36.2, U6.34 (VDD18PLL)
unnamed: R15.2, U7.3 (OUT)
unnamed: R24.2, U10.12 (ILIM)
unnamed: R21.2, U10.14 (TMR)
unnamed: R33.1, U10.1 (TS)
unnamed: R25.2, U11.7 (KEY0)
unnamed: R26.2, U11.6 (KEY1)
unnamed: R27.2, U11.5 (KEY2)
unnamed: R28.2, U11.4 (KEY3)
unnamed: R29.2, U11.3 (KEY4)
unnamed: R34.1, U11.12 (~RESET)
USB_D+: J3.A6 (D+), J3.B6 (D+), U3.10 (DP)
USB_D-: J3.A7 (D-), J3.B7 (D-), U3.9 (DM)

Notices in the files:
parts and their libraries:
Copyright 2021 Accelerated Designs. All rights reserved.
